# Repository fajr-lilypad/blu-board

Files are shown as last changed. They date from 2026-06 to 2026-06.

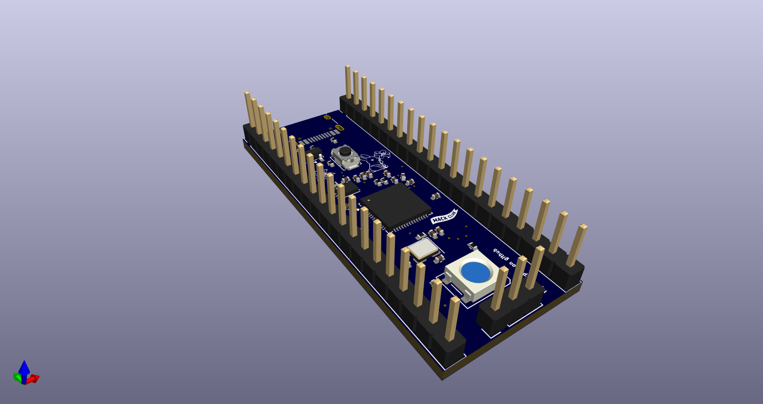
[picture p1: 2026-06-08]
PCB Design/3dViewerFront.png

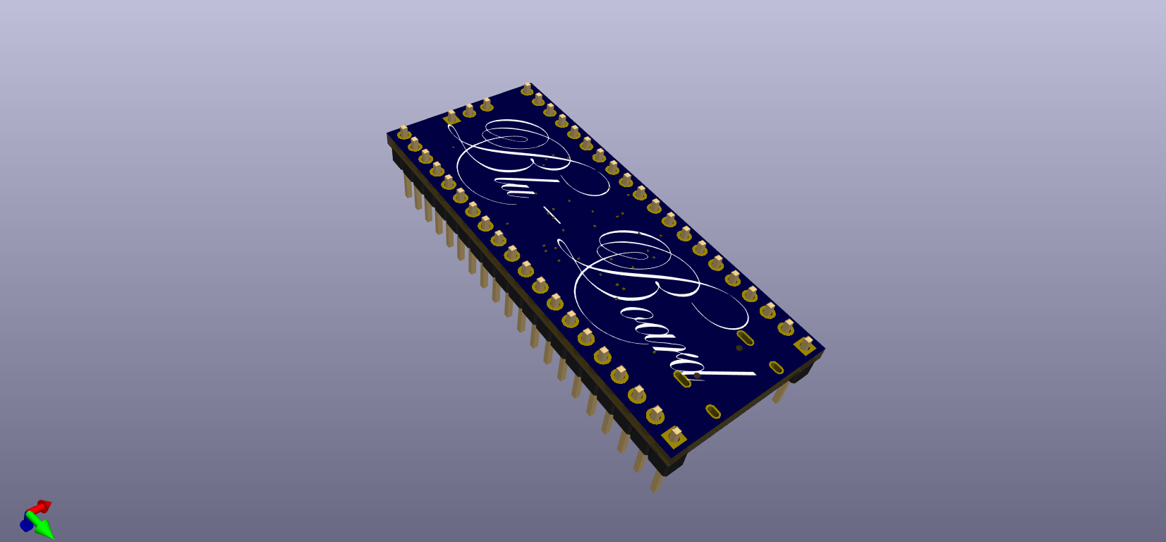
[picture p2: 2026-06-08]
PCB Design/3dViewerBack.png

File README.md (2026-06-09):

# blu-board

Blu-Board is a custom devboard (my first!) Built off of a RP2040, this is a more advanced project so I could get used to complex routing, placement, and assembly. I started this off using a guide, which I consulted for fabrication, materials, and for when I ran into DRC errors I'm not familair with. I decided to customize it and add a special LED that will glow periodically. I made it with the intention of creating a PCB that would be my most diificult to route yet in order to challenge myself, and it definetly was! I had a goal of creating a clean and compact pcb design, one that is minimalist and just allows you to have direct access to the RP2040, and will fit into tight spaces! Breadboard friendly and with an LED for code-tetsting, this is a friendly board to use with my beginner projects, with an LED for simple debugging and testing :)




## PCB Layout 

This took a lot of time, but was worth it in the end! It taught me a lot about routing, thermal reliefs, and mindful placement. It was my first time working with a flash memory card or a crystal oscillator in a pcb, too!
<table>
  <tr>
    <td>
      
    </td>
    <td>
    
    </td>
  </tr>
</table>

## Schematic Wiring Diagram



## Zine



## BOM
| Item | Qty | Purpose | Price | Source | Link |
| :--- | :---: | :--- | :---: | :--- | :--- |
| Raspberry Pi RP2040 | 1 | Microcontroller | $0.80 | PiShopUSA | [Link](https://www.pishop.us/product/raspberry-pi-rp2040/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) |
| 1x20 Pin Header | 2 | Pins | $1.34 | Mikroe | [Link](https://www.mikroe.com/1x20-male-pin-header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) |
| 0.1uF C | 12 | Capacitor | $3.84 | Sparkfun | [Link](https://www.sparkfun.com/capacitor-ceramic-0-1uf.html) |
| 5.1k R | 2 | Resistor | $0.08 | Electronix Express | [Link](https://www.elexp.com/products/130155-1kres-1-watt-5-5-1-k-ohm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) |
| 10uF C | 2 | Capacitor | $0.40 | DigiKey | [Link](https://www.digikey.com/en/products/detail/kyocera-avx/REA0511100M025K/20096372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) |
| 1K R | 2 | Resistor | $0.20 | DigiKey | [Link](https://www.digikey.com/en/products/detail/yageo/MFR-25FTF52-1K/9140604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) |
| 1x03 Pin Header | 1 | Pins | $0.23 | Mouser Electronics | [Link](https://www.mouser.com/ProductDetail/Harwin/M22-2510305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) |
| 1uF C | 2 | Capacitor | $0.40 | DigiKey | [Link](https://www.digikey.com/en/products/detail/kyocera-avx/REA05111R0M050K/20096513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) |
| 33pf C | 2 | Capacitor | $1.12 | DigiKey | [Link](https://www.digikey.com/en/products/detail/murata-electronics/RCE5C2A330J0M1H03A/4277083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) |
| WS2812B | 1 | LED | $0.10 | Ebee | [Link](https://www.ebee.com/product-detail/worldsemi-ws2812b-v5-w_617514.html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) |
| MCP1700x-330xxTT | 1 | Regulator | $0.51 | DigiKey | [Link](https://www.digikey.com/en/products/detail/microchip-technology/MCP1700T-3302E-TT/652676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) |
| USB C Receptacle | 1 | Connector | $0.91 | DigiKey | [Link](https://www.digikey.com/en/products/detail/gct/USB4085-GF-A/9859662?msockid=2e5d5b722df0614517334d312c7660e6) |
| 12 MHz Crystal SMD | 1 | Crystal | $0.50 | Mouser Electronics | [Link](https://www.mouser.com/ProductDetail/Wurth-Elektronik/830105420809?qs=hd1VzrDQEGhFJmLFyoYByw%3D%3D) |
| 330 Ohm Chip R | 1 | Resistor | $0.10 | DigiKey | [Link](https://www.digikey.com/en/products/detail/yageo/RT0402FRE07330RL/1071958) |
| W25Q128JVS | 1 | Memory Chip | $1.87 | Buy Display | [Link](https://www.buydisplay.com/new-winbond-ic-chip-flash-128m-bit-w25q128jv-sop8-package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) |
| 27K R | 2 | Resistor | $0.42 | Newark | [Link](https://www.newark.com/multicomp-pro/mf25-27k/res-27k-250mw-axial-metal-film/dp/38K5324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) |
| 10K R | 1 | Resistor | $0.19 | Newark | [Link](https://www.newark.com/multicomp-pro/mf12-10k/res-10k-125mw-axial-metal-film/dp/38K5401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) |
| SW Push | 1 | Button | $0.11 | SameSky | [Link](https://www.sameskydevices.com/product/switches/tactile-switches/ts02-66-60-bk-260-lcr-d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) |
| PCB Order | 1 | PCB | $2.10 | JLCPCB | [Link](https://cart.jlcpcb.com/quote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) |
| **Subtotal** | | | **$15.22** | | |

## Notes and Acknoweldgements
Thank you to the hackclub and fallout team for making this possible!

Thank you user KaiPereira for a super helpful guide on devboards and all things PCB! I learned so much!

"Blu - Board" font courtesy of Alit Design Studio

All artwork belongs to respective creators.

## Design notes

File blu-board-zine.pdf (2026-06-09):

# Blu - Board

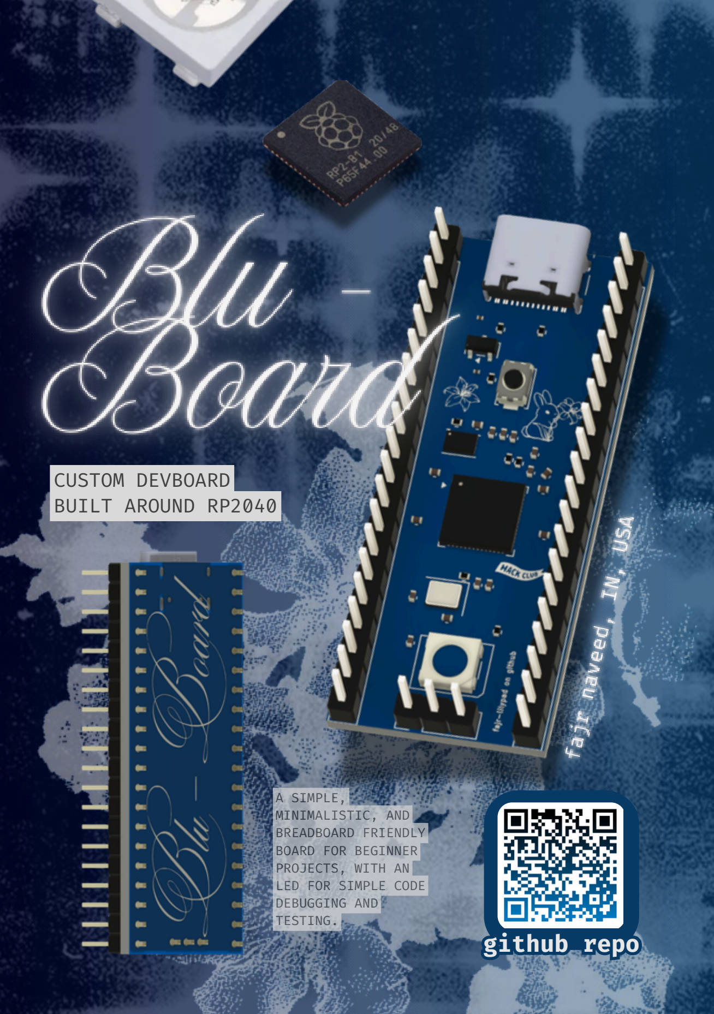
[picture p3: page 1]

## CUSTOM DEVBOARD BUILT AROUND RP2040

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
d, I

### N, USA

A SIMPLE,
MINIMALISTIC, AND
BREADBOARD FRIENDLY
BOARD FOR BEGINNER
PROJECTS, WITH AN
LED FOR SIMPLE CODE
DEBUGGING AND
TESTING.

# github repo

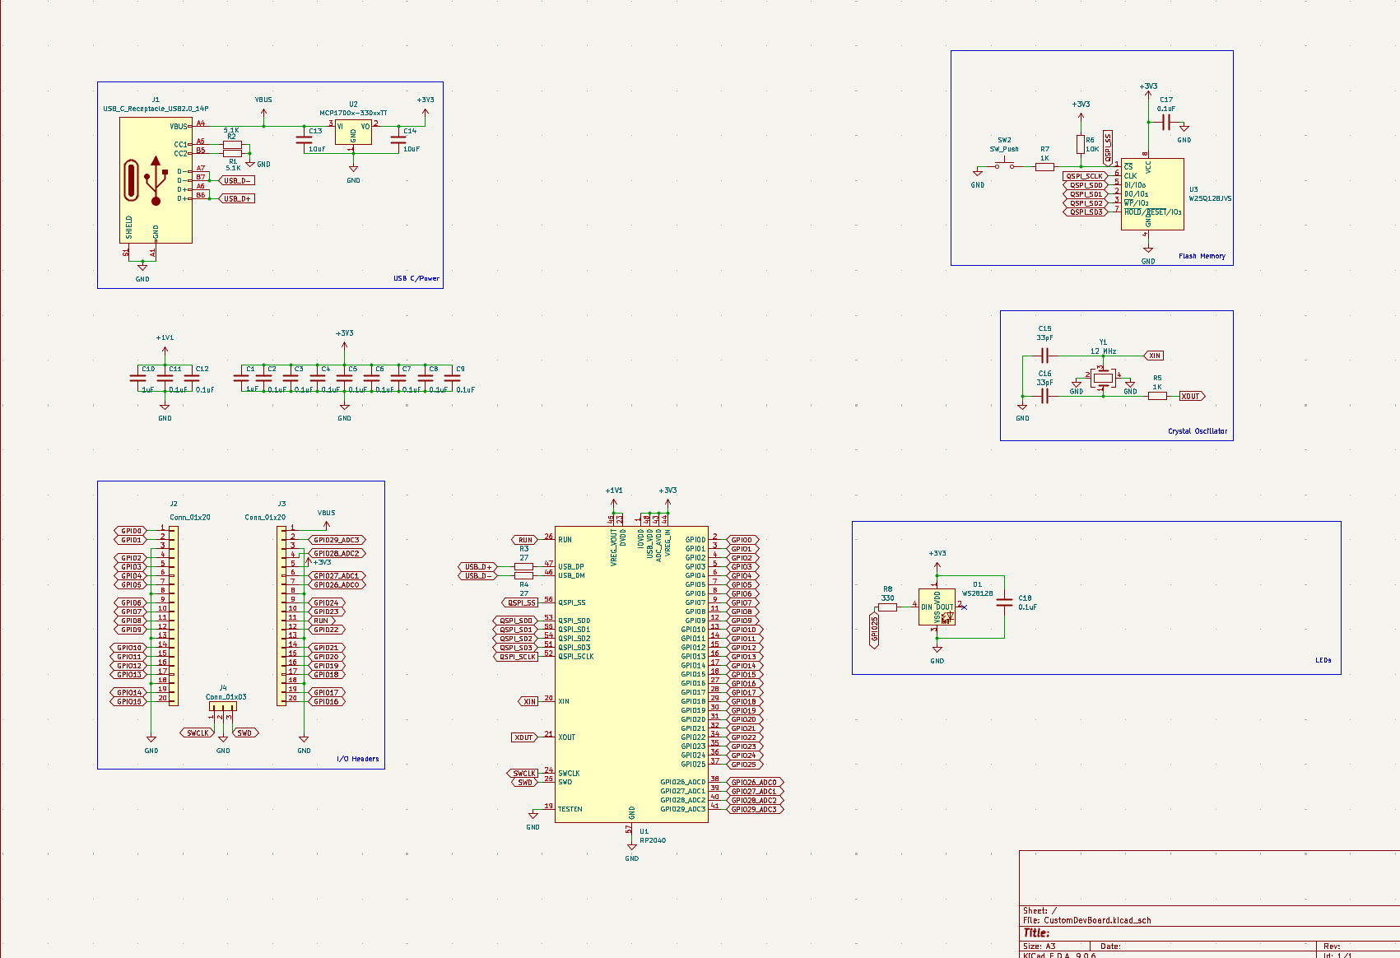
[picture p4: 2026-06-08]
Schematic/Schematic.png

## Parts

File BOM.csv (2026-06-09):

Item | # | Purpose | Price | Source | Link
Rasberry Pi 2040 | 1 | Microcontroller | $0.80 | PiShopUSA | https://www.pishop.us/product/raspberry-pi-rp2040/
1x20 Pin Header | 2 | Pins | $1.34 | Mikroe | https://www.mikroe.com/1x20-male-pin-header
0.1uF C | 12 | Capacitor | $3.84 | Sparkfun | https://www.sparkfun.com/capacitor-ceramic-0-1uf.html
5.1k R | 2 | Resistor | $0.08 | Electronix Express | https://www.elexp.com/products/130155-1kres-1-watt-5-5-1-k-ohm?variant=42620564504804&country=US&currency=USD
10uF C | 2 | Capacitor | $0.40 | DigiKey | https://www.digikey.com/en/products/detail/kyocera-avx/REA0511100M025K/20096372?gclsrc=aw.ds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
1K R | 2 | Resistor | $0.20 | DigiKey | https://www.digikey.com/en/products/detail/yageo/MFR-25FTF52-1K/9140604?gclsrc=aw.ds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
1x03 Pin Header | 1 | Pins | $0.23 | Mouser Electronics | https://www.mouser.com/ProductDetail/Harwin/M22-2510305?qs=Z7IUn5gUMVONkEjocUd7kg%3D%3D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
1uF C | 2 | Capacitor | $0.40 | DigiKey | https://www.digikey.com/en/products/detail/kyocera-avx/REA05111R0M050K/20096513?gclsrc=aw.ds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
33pf C | 2 | Capacitor | $1.12 | DigiKey | https://www.digikey.com/en/products/detail/murata-electronics/RCE5C2A330J0M1H03A/4277083?gclsrc=aw.ds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
WS2812B | 1 | LED | $0.10 | Ebee | https://www.ebee.com/product-detail/worldsemi-ws2812b-v5-w_617514.html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
MCP1700x-330xxTT | 1 | Regulator | $0.51 | DigiKey | https://www.digikey.com/en/products/detail/microchip-technology/MCP1700T-3302E-TT/652676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
USB C Receptacle | 1 | Connector | $0.91 | DigiKey | https://www.digikey.com/en/products/detail/gct/USB4085-GF-A/9859662?msockid=2e5d5b722df0614517334d312c7660e6
12 MHz Crystal SMD | 1 | Crystal | $0.50 | Mouser Electronics | https://www.mouser.com/ProductDetail/Wurth-Elektronik/830105420809?qs=hd1VzrDQEGhFJmLFyoYByw%3D%3D
330 Ohm Chip R | 1 | Resistor | $0.10 | DigiKey | https://www.digikey.com/en/products/detail/yageo/RT0402FRE07330RL/1071958
W25Q128JVS | 1 | Memory Chip | $1.87 | Buy Display | https://www.buydisplay.com/new-winbond-ic-chip-flash-128m-bit-w25q128jv-sop8-package
27K R | 2 | Resistor | $0.42 | Newark | https://www.newark.com/multicomp-pro/mf25-27k/res-27k-250mw-axial-metal-film/dp/38K5324?cjdata=MXxOfDB8WXww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
10K R | 1 | Resistor | $0.19 | Newark | https://www.newark.com/multicomp-pro/mf12-10k/res-10k-125mw-axial-metal-film/dp/38K5401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
SW Push | 1 | Button | $0.11 | SameSky | https://www.sameskydevices.com/product/switches/tactile-switches/ts02-66-60-bk-260-lcr-d?gad_source=1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
PCB Order | 1 | PCB | $2.10 | JLCPCB | https://cart.jlcpcb.com/quote?stencilLayer=2&stencilWidth=100&stencilLength=100&stencilCounts=5&plateType=1
 |  | Subtotal | $15.22

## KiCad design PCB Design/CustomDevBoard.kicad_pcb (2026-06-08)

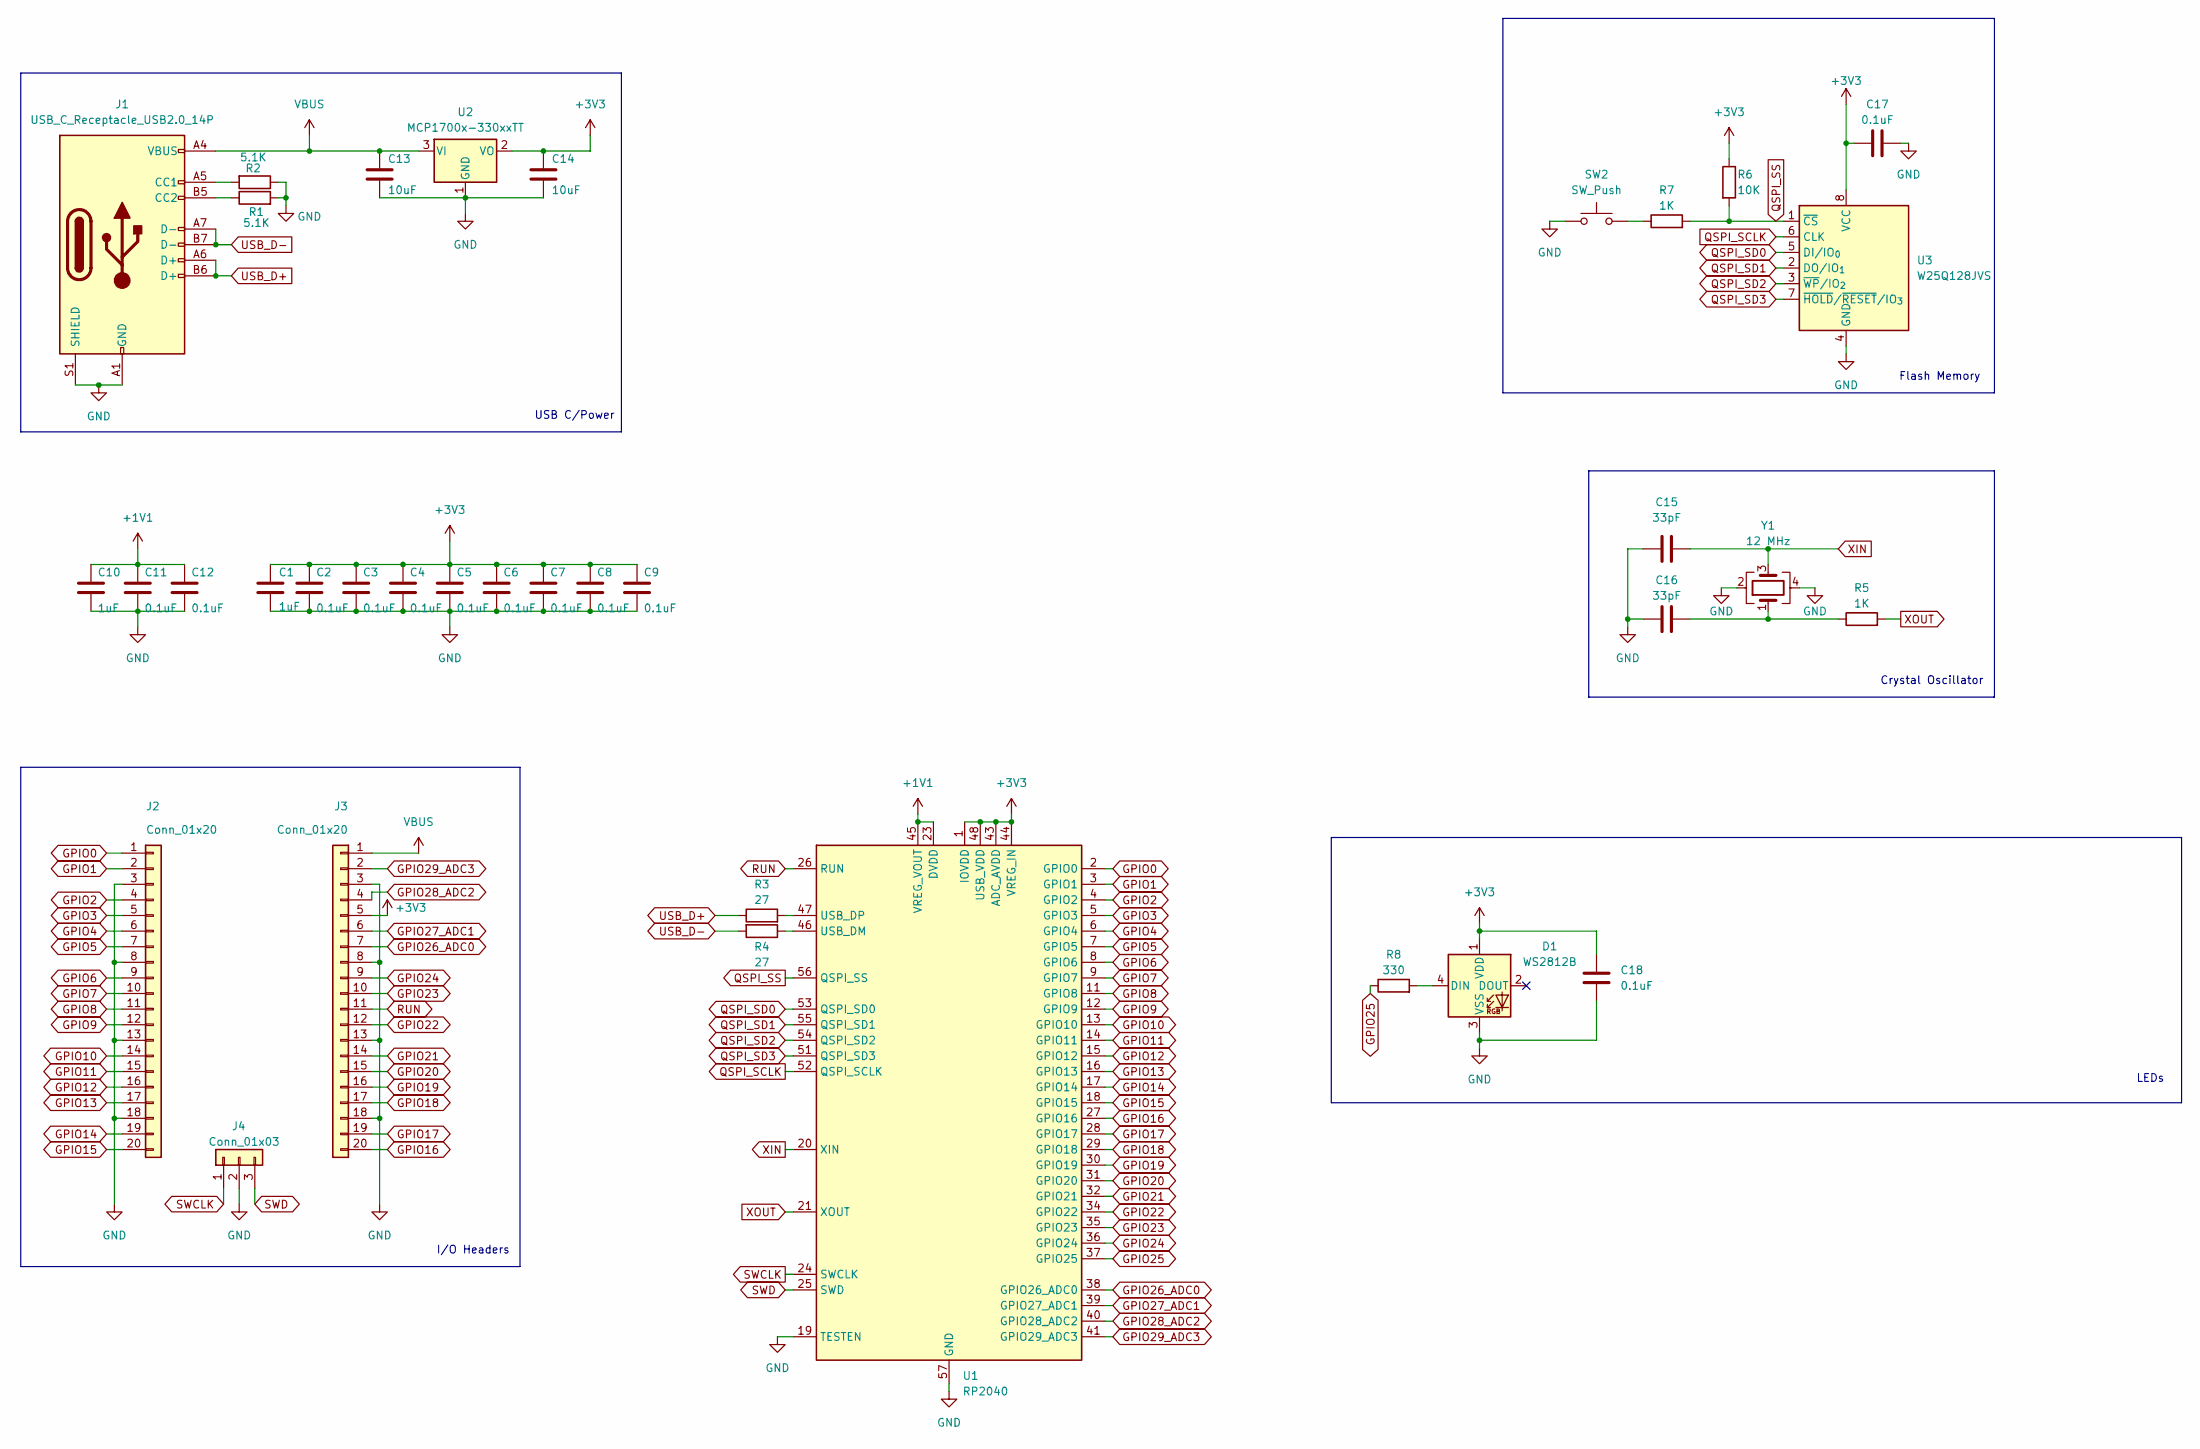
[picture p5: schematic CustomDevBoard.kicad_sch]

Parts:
C1, C10: 1uF; C_0402_1005Metric
C2, C3, C4, C5, C6, C7, C8, C9, C11, C12, C17, C18: 0.1uF; C_0402_1005Metric
C13, C14: 10uF; C_0201_0603Metric
C15, C16: 33pF; C_0402_1005Metric
D1: WS2812B; LED_WS2812B_PLCC4_5.0x5.0mm_P3.2mm
J1: USB_C_Receptacle_USB2.0_14P; USB_C_Receptacle_HRO_TYPE-C-31-M-12
J2, J3: Conn_01x20; PinHeader_1x20_P2.54mm_Vertical
J4: Conn_01x03; PinHeader_1x03_P2.54mm_Vertical
R1, R2: 5.1K; R_0402_1005Metric
R3, R4: 27; R_0402_1005Metric
R5, R7: 1K; R_0402_1005Metric
R6: 10K; R_0402_1005Metric
R8: 330; R_0402_1005Metric
SW2: SW_Push; SW_Push_SPST_NO_Alps_SKRK
U1: RP2040; QFN-56-1EP_7x7mm_P0.4mm_EP3.2x3.2mm
U2: MCP1700x-330xxTT; SOT-23
U3: W25Q128JVS; Winbond_USON-8-1EP_3x2mm_P0.5mm_EP0.2x1.6mm
Y1: 12 MHz; Crystal_SMD_3225-4Pin_3.2x2.5mm

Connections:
+1V1: C10.1, C11.1, C12.1, U1.23 (DVDD), U1.45 (VREG_VOUT), U1.50 (DVDD)
+3V3: C1.1, C2.1, C3.1, C4.1, C5.1, C6.1, C7.1, C8.1, C9.1, C14.1, C17.1, C18.1, D1.1 (VDD), J3.5, R6.1, U1.1 (IOVDD), U1.10 (IOVDD), U1.22 (IOVDD), U1.33 (IOVDD), U1.42 (IOVDD), U1.43 (ADC_AVDD), U1.44 (VREG_IN), U1.48 (USB_VDD), U1.49 (IOVDD), U2.2 (VO), U3.8 (VCC)
GND: C1.2, C2.2, C3.2, C4.2, C5.2, C6.2, C7.2, C8.2, C9.2, C10.2, C11.2, C12.2, C13.2, C14.2, C15.1, C16.2, C17.2, C18.2, D1.3 (VSS), J1.A1 (GND), J1.A12 (GND), J1.B1 (GND), J1.B12 (GND), J1.S1 (SHIELD), J2.3, J2.8, J2.13, J2.18, J3.3, J3.8, J3.13, J3.18, J4.2, R1.2, R2.1, SW2.1, U1.19 (TESTEN), U1.57 (GND), U2.1 (GND), U3.4 (GND), Y1.2, Y1.4
GPIO0: J2.1, U1.2 (GPIO0)
GPIO1: J2.2, U1.3 (GPIO1)
GPIO2: J2.4, U1.4 (GPIO2)
GPIO3: J2.5, U1.5 (GPIO3)
GPIO4: J2.6, U1.6 (GPIO4)
GPIO5: J2.7, U1.7 (GPIO5)
GPIO6: J2.9, U1.8 (GPIO6)
GPIO7: J2.10, U1.9 (GPIO7)
GPIO8: J2.11, U1.11 (GPIO8)
GPIO9: J2.12, U1.12 (GPIO9)
GPIO10: J2.14, U1.13 (GPIO10)
GPIO11: J2.15, U1.14 (GPIO11)
GPIO12: J2.16, U1.15 (GPIO12)
GPIO13: J2.17, U1.16 (GPIO13)
GPIO14: J2.19, U1.17 (GPIO14)
GPIO15: J2.20, U1.18 (GPIO15)
GPIO16: J3.20, U1.27 (GPIO16)
GPIO17: J3.19, U1.28 (GPIO17)
GPIO18: J3.17, U1.29 (GPIO18)
GPIO19: J3.16, U1.30 (GPIO19)
GPIO20: J3.15, U1.31 (GPIO20)
GPIO21: J3.14, U1.32 (GPIO21)
GPIO22: J3.12, U1.34 (GPIO22)
GPIO23: J3.10, U1.35 (GPIO23)
GPIO24: J3.9, U1.36 (GPIO24)
GPIO25: R8.1, U1.37 (GPIO25)
GPIO26_ADC0: J3.7, U1.38 (GPIO26_ADC0)
GPIO27_ADC1: J3.6, U1.39 (GPIO27_ADC1)
GPIO28_ADC2: J3.4, U1.40 (GPIO28_ADC2)
GPIO29_ADC3: J3.2, U1.41 (GPIO29_ADC3)
unnamed: C16.1, R5.1, Y1.1
unnamed: D1.4 (DIN), R8.2
unnamed: J1.A5 (CC1), R2.2
unnamed: J1.B5 (CC2), R1.1
unnamed: R7.1, SW2.2
unnamed: R4.1, U1.46 (USB_DM)
unnamed: R3.2, U1.47 (USB_DP)
QSPI_SCLK: U1.52 (QSPI_SCLK), U3.6 (CLK)
QSPI_SD0: U1.53 (QSPI_SD0), U3.5 (DI/IO_{0})
QSPI_SD1: U1.55 (QSPI_SD1), U3.2 (DO/IO_{1})
QSPI_SD2: U1.54 (QSPI_SD2), U3.3 (~WP/IO_{2})
QSPI_SD3: U1.51 (QSPI_SD3), U3.7 (~HOLD/~RESET/IO_{3})
QSPI_SS: R6.2, R7.2, U1.56 (QSPI_SS), U3.1 (~CS)
RUN: J3.11, U1.26 (RUN)
SWCLK: J4.1, U1.24 (SWCLK)
SWD: J4.3, U1.25 (SWD)
USB_D+: J1.A6 (D+), J1.B6 (D+), R3.1
USB_D-: J1.A7 (D-), J1.B7 (D-), R4.2
VBUS: C13.1, J1.A4 (VBUS), J1.A9 (VBUS), J1.B4 (VBUS), J1.B9 (VBUS), J3.1, U2.3 (VI)
XIN: C15.2, U1.20 (XIN), Y1.3
XOUT: R5.2, U1.21 (XOUT)

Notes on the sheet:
Crystal Oscillator
I/O Headers
LEDs
USB C/Power
Flash Memory

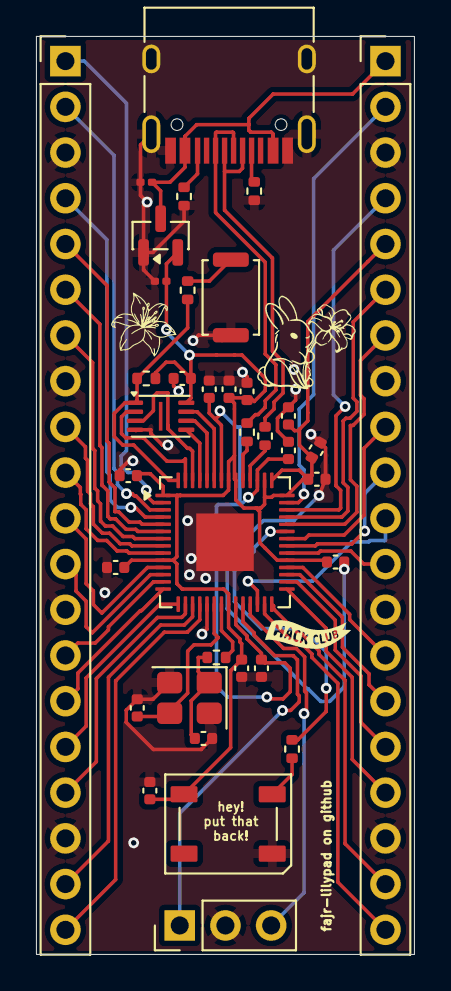
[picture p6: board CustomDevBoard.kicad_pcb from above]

Board: 2 copper layers, 21.0 x 51.0 mm, 36 parts (0 on the bottom side), 54 nets.

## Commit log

2026-06-08 Rename CustomDevBoard.kicad_pcb to PCB Design/CustomDevBoard.kicad_pcb
    [CustomDevBoard.kicad_pcb]
2026-06-08 Rename CustomDevBoard.kicad_prl to PCB Design/ CustomDevBoard.kicad_prl
2026-06-08 Rename CustomDevBoard.kicad_pro to PCB Design/CustomDevBoard.kicad_pro
2026-06-08 Rename CustomDevBoard.kicad_sch to PCB Design/CustomDevBoard.kicad_sch
    [CustomDevBoard.kicad_sch]
2026-06-08 Rename Blue Board Assembly.f3z to CAD/Blu - Board Assembly.f3z
    [Blu - Board Assembly.f3z, Blue Board Assembly.f3z]
2026-06-08 Rename Screenshot 2026-06-08 152114.png to Schematic/Schematic.png
2026-06-09 Rename Blue Board Assembly.step to Blu - Board Assembly.step
    [Blu - Board Assembly.step]
